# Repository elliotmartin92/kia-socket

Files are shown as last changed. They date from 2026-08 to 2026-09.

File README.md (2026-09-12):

# Automotive 120V AC Outlet Sub-Housing & Safety Interlock Mechanism
## Parametric 3D CAD Model & Generator Documentation

This repository contains the complete parametric CAD generation pipeline for the intermediate sub-housing baseplate and safety rocker mechanism of an **in-cabin automotive 120V AC US power outlet assembly**.

---

## System Architecture & Functional Overview

The complete automotive AC power outlet assembly consists of three primary mating components:
1. **Front Outlet Receptacle Bezel / Faceplate**: Exposed inside the vehicle cabin, providing the standard US NEMA 1-15 / 5-15 AC plug slots.
2. **Intermediate Sub-Housing Baseplate & Rocker Mechanism (THIS REPOSITORY)**:
   - **Primary Function 1: Current-Carrying Busbar & Terminal Retention**: Securely locates and retains the formed copper/brass contact pieces and busbar strips within precision guide brackets (Brackets 1–4) and backside slit channels, transferring high AC current from the rear electronics module directly into the front receptacle prongs.
   - **Primary Function 2: Active Plug Insertion Sensing & Power Safety Interlock**: Integrates a spring-biased/pivot rocker mechanism mounted inside heavy-duty retention towers. When the **right plug prong (blade)** is inserted into the outlet, it physically depresses the rocker's angled input cam tab ($105^\circ$ direct rocker arm). This rotates the pivot shaft in its cradles, driving the extended plunger arm downward ($Z \le -6.50\text{ mm}$) through the baseplate floor pass-through hole into a PCB-mounted tactile microswitch. This signals the inverter/control module that a plug is physically seated, ensuring the outlet **delivers 120V AC power only when a plug is actively inserted** (preventing idle power draw and electric shock hazards).
3. **Rear Electronics / Inverter & Control Board Module**: Houses the DC-to-AC power inverter, logic controller, supply terminal feeds, and the momentary interlock switch.

---

## 1. Quick Start & Regeneration Commands

To rebuild all 3D CAD assets and 2D/3D annotated blueprints from source:

```bash
# Build main baseplate CAD models (part.stl, part.obj, complete_assembly.stl)
py -3 build_part.py

# Build anti-spreading tower prong clamps (tower_clamp.stl, tower_clamps_pair.stl)
py -3 build_clamp.py

# Generate high-resolution dimensioned feature blueprints (labeled_part_preview.png)
py -3 generate_labeled_preview.py
```

### Generated Output Files
| File | Description |
| :--- | :--- |
| **`part.stl`** / **`part.obj`** | Main baseplate with **100% planar flat bottom ($Z = 0.00\text{ mm}$)** for support-free 3D printing. Tower prongs remain 100% solid and full-thickness, featuring robust additive external side retention ledges (**$+0.70\text{ mm}$ protrusion in $X$**, $Z \in [12.40, 13.60]\text{ mm}$) on outer lateral faces. Baseplate floor features enlarged $2.90 \times 5.10\text{ mm}$ female detent sockets for slit inserts. |
| **`shaft_rocker.stl`** / **`shaft_rocker.obj`** | Separate 3D-printable enlarged heavy-duty shaft/rocker mechanism with $\varnothing 2.80\text{ mm}$ axle pins, $\varnothing 4.20\text{ mm}$ hub, input cam, and $\ge 6.5\text{ mm}$ reach plunger. Pre-oriented flat on build bed ($Z = 0.00\text{ mm}$). |
| **`shaft_rocker_assembled.stl`** | Shaft/rocker mechanism positioned in exact assembly coordinates seated in the towers. |
| **`shaft_rocker.scad`** | OpenSCAD parametric source file for the shaft/rocker mechanism. |
| **`tower_clamp_bridge.stl`** / **`tower_clamp.stl`** | **Unified 1-Piece Monolithic Bridge Clamp**: Single unified component joining Left and Right clamps across a **$14.10\text{ mm}$ rigid rear gantry span** ($X \in [2.20, 16.30]\text{ mm}$). Both sides **mutually anchor each other**, clamping both towers from their outer lateral faces with **$0.65\text{ mm}$ deep inward undercut snap hooks** at $Z = 12.40\text{ mm}$ (providing $>4.5\times$ greater mechanical retention area; physically impossible to rock or fall off). Features clearance arches over both $\varnothing 2.80\text{ mm}$ axle pins ($\ge 0.30\text{ mm}$ radial air gap, zero pin friction!). Pre-oriented flat on print bed ($Z = 0.00\text{ mm}$, $85.15\text{ mm}^3$ volume, 100% watertight, support-free, $\sim 3\text{ min}$ print time). |
| **`tower_clamp_left.stl`** / **`tower_clamp_right.stl`** | Individual Left and Right clamp variants for modular installation. |
| **`tower_clamps_pair.stl`** | Pre-arranged pair of individual clamps on a single build plate. |
| **`tower_clamp.scad`** | OpenSCAD parametric source file for the tower clamps. |
| **`slit_insert.stl`** / **`slit_insert.obj`** | Separate 3D-printable backside slit wall insert with enlarged, sliceable registration key (**$2.60 \times 4.80\text{ mm}$** with solid **$0.70\text{ mm}$ walls**, impossible to drop in slicing) and $0.60\text{ mm} \times 45^\circ$ non-breaching polarization corner bevel. |
| **`slit_inserts_pair.stl`** | Two inserts pre-arranged side-by-side on a single build plate for 1-click 3D printing. |
| **`cooling_tower.stl`** / **`cooling_tower.obj`** | Sacrificial cooling column ($\varnothing 8.00\text{ mm} \times 20.50\text{ mm}$ tall) to guarantee dedicated cooling time per layer on delicate baseplate tower tips ($Z = 14.09\text{ mm}$) and shaft rocker tips ($Z = 19.86\text{ mm}$). |
| **`complete_assembly.stl`** / **`complete_assembly.obj`** | Complete 1-click 3D print plate with the main baseplate, both separate slit inserts, shaft rocker, sacrificial cooling tower, and the **Unified Monolithic Bridge Clamp** pre-arranged side-by-side on the **same flat print plane ($Z = 0.00\text{ mm}$)**. |
| **`part.scad`** | OpenSCAD source file representing the exact baseplate geometry. |
| **`labeled_part_preview.png`** | 3-panel blueprint showing top-down dimensioned feature map, 3D isometric assembly, and kinematic stroke cross-section. |
| **`part_preview.png`** | 3-panel multi-angle view (Top-Down, 3D Perspective, Bottom View). |

---

## 2. Coordinate System & Global Units

- **Units**: All dimensions are in **millimeters ($\text{mm}$)**.
- **Origin $(0, 0, 0)$**: Geometric center of the main body circle/profile.
- **Scale Factor**: Calibrated from SVG pixel coordinates:
  $$\text{SCALE} = 0.349787\text{ mm/pixel}, \quad X_0 = 128.65\text{ px}, \quad Y_0 = 128.65\text{ px}$$
- **$Z$-Axis Elevations (Main Part)**:
  - $Z = 0.00\text{ mm}$: 100% Flat build-plate datum (zero support needed under main floor).
  - $Z \in [0.00, 1.00]\text{ mm}$: Solid base floor plate ($1.00\text{ mm}$ thick).
  - $Z \in [1.00, 1.50]\text{ mm}$: Internal floor stiffener grid ribs ($0.50\text{ mm}$ tall).
  - $Z \in [1.00, 4.60]\text{ mm}$: Guide brackets ($4.60\text{ mm}$ total height).
  - $Z \in [1.00, 6.77]\text{ mm}$: Outer perimeter wall, snap clip stems, bottom arch wall, and bridge rib ($6.77\text{ mm}$ height).
  - $Z \in [1.00, 10.50]\text{ mm}$: Center curved feature with reinforced solid core and flat base ($10.50\text{ mm}$ total height).
  - $Z \in [1.00, 14.09]\text{ mm}$: Shaft support towers ($13.09\text{ mm}$ height above floor, total $14.09\text{ mm}$).
- **Separate Slit Insert Dimensions**:
  - $Z \in [0.00, 2.47]\text{ mm}$: Wall body ($3.80\text{ mm} \times 5.60\text{ mm}$ outer, $1.20\text{ mm} \times 3.50\text{ mm}$ inner clearance channel for $0.77\text{ mm} \times 3.10\text{ mm}$ part).
  - $Z \in [2.47, 3.32]\text{ mm}$: Indexing registration key ($2.00\text{ mm} \times 4.30\text{ mm} \times 0.85\text{ mm}$) with continuous $1.20\text{ mm} \times 3.50\text{ mm}$ core.

---

## 3. Comprehensive Feature Specifications

```
                              TOP TAB (8.20mm Wide, fits 8.33mm Gap)
                              +-------------------+
                             /                     \
                            /   [TOWER 1] [TOWER 2] \  <-- Shaft Axis (Y = 9.28mm, Z = 12.59mm)
           Snap Clip (135°) |      (2.45mm throat)  | Snap Clip (45°)
                            |   [Through-Hole]      |
                            |   5.35 x 4.51 mm      |
                            |                       |
       Left Side Ear (7.70)-|   [BRACKETS]          |- Right Side Ear (7.70mm Wide, fits 8.30mm Gap)
                            |   [CENTER ARCH WALL]  |
                            |   (10.50mm tall)      |
          Snap Clip (211.3°)|                       | Snap Clip (327.5°)
                            \   [SLIT 1]  [SLIT 2]  / (4.42mm from ears, 8.47mm from tabs)
                             \  1.20x3.50 1.20x3.50/
                              +---+             +---+
                              |   | [U-ARCH 5mm]|   |
                              |   | (7.95mm H)  |   |
                              +---+-------------+---+
                              LEFT TAB       RIGHT TAB
```

### 3.1. Bottom Central U-Arch & Inset Wall (Config 1)
- **Arch Interior Clearance Width**: **$5.00\text{ mm}$** ($R_{\text{inner}} = 2.50\text{ mm}$, centered on $X \in [-2.50, +2.50]\text{ mm}$).
- **Arch Wall Thickness**: **$1.20\text{ mm}$** ($R_{\text{outer}} = 3.70\text{ mm}$, $X \in [-3.70, +3.70]\text{ mm}$).
- **Total Outer Height in $Y$**: **$7.95\text{ mm}$**
  - Base at Inset Bottom Exterior Wall: $Y = -16.650\text{ mm}$
  - Outer Arch Apex: $Y = -8.700\text{ mm}$ ($-16.650 + 7.950\text{ mm}$)
  - Inner Arch Apex: $Y = -9.900\text{ mm}$ ($6.75\text{ mm}$ inner clearance height)
  - Semicircle Arc Center: $Y = -12.400\text{ mm}$ (Straight tangent legs: $4.25\text{ mm}$ in $Y$).
- **Inset Bottom Exterior Wall Notch**:
  - Inset depth: $1.889\text{ mm}$ in $+Y$ (from bottom tabs at $Y = -18.539\text{ mm}$ to inset wall at $Y = -16.650\text{ mm}$).
  - Notch outer sidewalls: placed at **$X = \pm 2.500\text{ mm}$**, aligning with the **interior sidewalls of the arch**.
  - Floor: Solid continuous $1.00\text{ mm}$ floor within the inset wall.

### 3.2. Shaft Support Towers with Heavy-Duty Reinforced Retention Cradles
- **Shaft Axis**: **$Y = 9.279\text{ mm}$, $Z = 12.59\text{ mm}$** ($\varnothing 3.00\text{ mm}$ shaft cradle socket, centered directly over the through-hole).
- **Left Tower**: $X \in [3.900, 5.400]\text{ mm}$ ($1.50\text{ mm}$ wall thickness).
- **Right Tower**: $X \in [13.100, 14.600]\text{ mm}$ ($1.50\text{ mm}$ thickness, $0.14\text{ mm}$ clearance right of through-hole).
- **Internal Clearance Between Towers**: **$7.70\text{ mm}$**.
- **Flared Trapezoidal Tower Profile (in Y-Z)**:
  - Base Length in $Y$: **$6.60\text{ mm}$** ($Y \in [6.250, 12.850]\text{ mm}$, shifted $-0.921\text{ mm}$ to align buttress base with top inner wall of Bracket 3 at $Y = 6.250\text{ mm}$).
  - Top Length in $Y$: **$5.63\text{ mm}$** ($Y \in [6.550, 12.180]\text{ mm}$).
- **Positive Heavy-Duty Snap-Fit Retention Cradle**:
  - Socket Diameter: **$\varnothing 3.00\text{ mm}$** (provides $0.20\text{ mm}$ running clearance with $\varnothing 2.80\text{ mm}$ shaft pin).
  - Retention throat constriction gap: **$2.60\text{ mm}$** ($0.20\text{ mm}$ firm positive mechanical interference with $\varnothing 2.80\text{ mm}$ shaft, $0.10\text{ mm}$ deflection per side to prevent snapping during insertion).
  - Wrap angle: **$240.0^\circ$** ($>60^\circ$ wrap beyond the equator), securely capturing and locking the axle against vertical ejection.
  - Wide $45^\circ$ lead-in bevel funnel expanding up to $3.73\text{ mm}$ opening at $Z = 14.09\text{ mm}$ for smooth self-centering downward press-fit insertion.
- **Left Tower Dual Lateral Buttress Struts**:
  - **Front Strut**: Base meets the top inner wall of Bracket 3 at **$Y = 6.250\text{ mm}$** ($X \in [1.90, 3.90\text{ mm}]$, $Y \in [6.250, 7.050\text{ mm}]$), sloping directly into the Left Tower at $Z = 13.70\text{ mm}$ with **zero encroachment into Bracket 3's sliding channel**.
  - **Rear Strut**: Full-height triangular rib ($1.20\text{ mm}$ thick in $Y$ at $Y \in [11.650, 12.850\text{ mm}]$, $X \in [1.90, 3.90\text{ mm}]$, $Z \in [1.00, 13.70\text{ mm}]$).
- **Right Tower Reinforcing Bridge Rib**: Spans $X \in [13.10, 20.00]\text{ mm}$ at $Y \in [7.50, 13.00]\text{ mm}$, connecting directly to the outer perimeter wall.

### 3.3. Curved Snap Clips (4x at $45^\circ, 135^\circ, 211.3^\circ, 327.5^\circ$)
- **Perimeter Positions**:
  - Top pair: $45^\circ$ and $135^\circ$ (halfway between top tab and side ears).
  - Bottom pair: **$211.3^\circ$ and $327.5^\circ$** (**$4.42\text{ mm}$ from respective side ears, $8.47\text{ mm}$ from respective bottom tabs**).
- **Wall Following**: Matches the exact curved contour of the outer ($R \approx 19.25\text{ mm}$) and inner ($R \approx 18.05\text{ mm}$) wall.
- **Beam Dimensions**: **$4.20\text{ mm}$ wide curved beam** (leaves $0.80\text{ mm}$ total margin / $0.40\text{ mm}$ per side for smooth insertion into $5.00\text{ mm}$ mating holes).
- **Flex Isolation**: Two $0.35\text{ mm}$ vertical through-slots (minimal printable clearance for a $0.4\text{ mm}$ nozzle) from $Z = 3.07\text{ mm}$ to $Z = 6.77\text{ mm}$ isolating the cantilever beam.
- **Hook Geometry ($Z \in [4.97, 6.77\text{ mm}$)**:
  - Undercut retention shelf at $Z = 4.97\text{ mm}$ projecting **$+2.49\text{ mm}$ radially outward** (refined $-0.10\text{ mm}$ from $2.59\text{ mm}$ to eliminate outer housing protrusion interference while maintaining deep engagement).
  - Sloped lead-in ramp tapering up to top outer wall apex at $Z = 6.77\text{ mm}$.
  - Inner wall face: 100% flush, smooth, continuous cylinder.
- **Built-In Sacrificial Support Towers (Twin-Prong Breakaway Fork Supports)**:
  - Sturdy base sitting flat on print bed ($Z = 0.00\text{ mm}$) with a wide adhesion foot ($1.80\text{ mm} \times 3.80\text{ mm}$) and solid lower trunk ($1.20\text{ mm} \times 3.40\text{ mm}$) up to $Z = 3.20\text{ mm}$.
  - **Twin Lateral Prongs & Prying Arch**: Splits into two vertical prongs centered at $Y = \pm 1.40\text{ mm}$ spanning across a $1.80\text{ mm}$ wide central prying arch window ($Z \in [3.20, 4.82]\text{ mm}$), directly supporting the outer lateral shelf corners ($0.25\text{ mm}$ margin to edges).
  - **Equal Contact Area ($0.90\text{ mm}^2$)**: Twin chisel breakaway tips ($2 \times [0.50\text{ mm} \times 0.90\text{ mm}] = 0.90\text{ mm}^2$, matching original area) at $Z = 4.94\text{ mm}$ ($0.03\text{ mm}$ micro-gap under the $Z = 4.97\text{ mm}$ shelf). Completely prevents edge droop while allowing effortless tool prying with zero marring.

### 3.4. Center Curved Feature with Reinforced Solid Core (Option 1)
- **Position**: Centered between Brackets 3 & 4 at $X_c = +6.279\text{ mm}$.
- **Width**: $4.30\text{ mm}$ ($X \in [4.129, 8.429]\text{ mm}$).
- **Depth in $Y$**: $1.62\text{ mm}$ (Base: $Y = -4.069\text{ mm}$, Apex: $Y = -2.449\text{ mm}$).
- **Offset**: $2.00\text{ mm}$ in $+Y$ above the horizontal bracket step datum ($Y = -6.069\text{ mm}$).
- **Monolithic Solid D-Shape Structure**:
  - Replaced the fragile $0.60\text{ mm}$ hollow C-shell with a **100% solid infill cross-section** ($5.46\text{ mm}^2$ solid area, $+52\%$ material increase).
  - Closed the bottom ($-Y$) with a **continuous solid flat back wall** along $Y = -4.069\text{ mm}$.
  - Preserves the identical top outer arc ($R_x = 2.15\text{ mm}, R_y = 1.62\text{ mm}$, apex at $Y = -2.449\text{ mm}$) with $+2.16\text{ mm}$ clearance to the plug blade.
  - Guaranteed clearance to OEM brass insert: **$+0.58\text{ mm}$ air gap** to the brass crossbar and **$+0.28\text{ mm}$ air gap** to Seating Rib 4.
  - Increases bending moment of inertia $I_{xx}$ by $+52\%$ ($0.658 \to 1.000\text{ mm}^4$) and shear fracture load capacity by $>3.6\times$, eliminating layer shear failures during disassembly.
- **Total Height**: **$10.50\text{ mm}$** ($Z \in [1.00, 10.50]\text{ mm}$).

### 3.5. Guide Brackets & Brass Seating Ribs (Looser Tolerances & 1.15mm Support Ribs)
- **Left Pair (Brackets 1 & 2)**: $X \in [-10.791, -1.766]\text{ mm}$.
- **Right Pair (Brackets 3 & 4)**: $X \in [+1.766, +10.791]\text{ mm}$.
- **Relaxed Looser Interior Tolerances (Brackets 1–4)**:
  - **Spine Channel Width ($X$)**: Widened from $6.856\text{ mm}$ to **$7.156\text{ mm}$** (provides **$+0.416\text{ mm}$ total sliding clearance** / $0.208\text{ mm}$ per side for the $6.74\text{ mm}$ OEM stamped brass contact strip, eliminating FDM print friction).
  - **Top Lead-In Throat Opening ($X$)**: Widened to **$3.500\text{ mm}$** ($+0.32\text{ mm} \text{ to } +0.35\text{ mm}$ wider funnel for smooth contact spring blade entry).
  - **Bottom Step Opening ($X$)**: Widened to **$3.800\text{ mm}$** ($+0.34\text{ mm}$ wider gap to easily pass the S-curved terminal leg).
  - **Internal Vertical Span ($Y$)**: Extended from $12.336\text{ mm}$ to **$12.600\text{ mm}$** ($Y \in [-6.200, +6.400]\text{ mm}$) to prevent axial binding.
  - **Top Hook Lead-In & Pocket ($Y$)**: Lower hook face raised to **$Y = 4.950\text{ mm}$**, upper pocket ceiling raised to **$Y = 6.400\text{ mm}$** (preserving full **$1.450\text{ mm}$** positive retention pocket depth).
- **Bracket Seating Ribs ($1.15\text{ mm}$ Elevation)**:
  - **Height**: **$1.15\text{ mm}$** protrusion above the floor ($Z \in [1.00, 2.15]\text{ mm}$) to elevate the brass contact piece.
  - **Inward Extension**: **$1.80\text{ mm}$** from each interior spine wall on both brackets of each pair.
  - **Central Open Corridor**: **$3.556\text{ mm}$** wide open central clearance along $X = \pm 6.28\text{ mm}$ for contact blade pinching and terminal pin clearance.
  - **Four Longitudinal $Y$ Stations**:
    - **Rib 1 (Top)**: Centered at **$Y = +5.250\text{ mm}$** ($Y \in [4.950, 5.550]\text{ mm}$), bottom edge meets the hook corner at $Y = 4.950\text{ mm}$ flush, forming a square seating corner under each hook.
    - **Rib 2**: Centered at **$Y = +1.950\text{ mm}$** ($Y \in [1.650, 2.250]\text{ mm}$).
    - **Rib 3**: Centered at **$Y = -1.350\text{ mm}$** ($Y \in [-1.650, -1.050]\text{ mm}$).
    - **Rib 4 (Bottom)**: Centered at **$Y = -4.650\text{ mm}$** ($Y \in [-4.950, -4.350]\text{ mm}$).
- **Bracket Total Height**: $4.60\text{ mm}$ ($Z \in [1.00, 5.60]\text{ mm}$).
- **Nominal Wall Thickness**: $0.85\text{ mm}$ to $0.93\text{ mm}$.

### 3.6. Backside Slit Protruding Bosses & Press-Fit Detent Inserts (Approach B: 100% Untouched Wall & Polarized Key)
- **Mating Component Fitment**: Custom engineered to comfortably pass a **$0.77\text{ mm} \text{ (thick in X)} \times 3.10\text{ mm} \text{ (long in Y)}$** metal contact blade.
- **Continuous Internal Through-Channel**: Sized at **$1.20\text{ mm} \text{ (in X)} \times 3.40\text{ mm} \text{ (in Y)}$** through both the insert and baseplate (**$+0.43\text{ mm}$ in X, $+0.30\text{ mm}$ in Y** generous sliding clearance to eliminate FDM print shrinkage binding).
- **Exact Slit Alignments**:
  - Left Slit Socket: Centered at **$X = -7.853\text{ mm}, Y = -13.589\text{ mm}$** (centered on Bracket 1 datum line).
  - Right Slit Socket: Centered at **$X = +8.453\text{ mm}, Y = -13.589\text{ mm}$** (exact OEM design alignment matching the vehicle mating plug).
- **100% UNTOUCHED Main Housing Perimeter Wall**:
  - The outer perimeter wall is **100% solid, continuous, and uniform $1.20\text{ mm}$ thick everywhere from $Z = 1.00\text{ mm}$ to $6.77\text{ mm}$** with **zero pockets, zero reliefs, and zero notches**.
  - All clearance routing is handled entirely on the insert indexing key and matching baseplate floor socket.
- **Main Baseplate Detent Sockets**: Two **$2.20\text{ mm} \times 4.40\text{ mm}$** female detent sockets cut through the $1.00\text{ mm}$ baseplate floor with a **$45^\circ$ corner chamfer** on the bottom-right of the right socket (and bottom-left of the left socket) to contour along the inner perimeter wall with a **$0.35\text{ mm}$ clean clearance margin**.
- **Separate Slit Inserts (`slit_insert.stl` & `slit_inserts_pair.stl`)**:
  - **$2.20\text{ mm}$ Sloped Outer Shroud Body**: $15.8^\circ$ draft angle tapering from a $2.70\text{ mm} \times 4.80\text{ mm}$ base shoulder down to **$2.20\text{ mm} \text{ (width)} \times 4.20\text{ mm} \text{ (length)}$** at the outer bottom face ($Z = 0.00\text{ mm}$), ensuring the shroud sits flush inside the $X = 9.812\text{ mm}$ outer perimeter wall edge with zero collision.
  - **1-Way Polarized Chamfered Indexing Key**: $1.80\text{ mm} \times 4.00\text{ mm}$ raised boss ($0.85\text{ mm}$ tall, $Z \in [2.47, 3.32]\text{ mm}$) featuring a **$45^\circ$ chamfered indexing corner** that prevents inserting the part backwards or rotated $180^\circ$.
  - **Fit Clearance**: **$0.40\text{ mm}$ total clearance ($0.20\text{ mm}$ per side)** into the baseplate detent socket for smooth, firm press-fit seating without binding.
  - **Flush Horizontal Seating Shoulder**: Sits flat against the baseplate bottom face ($Z = 0.00\text{ mm}$).
- **Complete Assembly Build Plate Layout**: `complete_assembly.stl` arranges the main baseplate, both separate slit inserts, shaft rocker, and sacrificial cooling tower flat on the **same build plane ($Z = 0.00\text{ mm}$)** side-by-side for 1-click support-free 3D printing.

### 3.7. Left and Right Side Ears (8.20mm Width for 8.30mm Enclosure Gap)
- **Position**: Left Side Ear at $X \approx -21.075\text{ mm}$, Right Side Ear at $X \approx +20.200\text{ mm}$ (centered at $Y = 0.00\text{ mm}$).
- **Outer Width in $Y$**: **$8.20\text{ mm}$** ($Y \in [-4.10, +4.10]\text{ mm}$).
- **Mating Enclosure Gap**: $8.30\text{ mm}$ (leaves $0.10\text{ mm}$ total sliding clearance / $0.05\text{ mm}$ per side for a smooth, bind-free sliding fit into the chassis guide slots).

### 3.8. Top Tab (8.20mm Width for 8.33mm Enclosure Gap)
- **Position**: Symmetrically centered along $X = 0.00\text{ mm}$ ($X \in [-4.10, +4.10]\text{ mm}$, Top apex at $Y = 20.01\text{ mm}$).
- **Outer Width in $X$**: **$8.20\text{ mm}$**.
- **Mating Enclosure Gap**: $8.33\text{ mm}$ (leaves $0.13\text{ mm}$ total sliding clearance / $0.065\text{ mm}$ per side for a clean, centered fit into the chassis top indexing slot).

### 3.9. Internal Floor Stiffener Grid
- **Pitch**: $5.20\text{ mm}$ (in $X$) $\times 3.20\text{ mm}$ (in $Y$).
- **Thickness & Height**: $0.60\text{ mm}$ thick, $0.50\text{ mm}$ tall ($Z \in [1.00, 1.50]\text{ mm}$).
- **Connectivity**: Connects directly into outer perimeter walls; excluded under bracket pairs and bottom zone ($Y < -7.17\text{ mm}$).

### 3.10. Enlarged Heavy-Duty Shaft & Rocker Mechanism (PCB Button Actuator)
- **Pivot Axle & Structural Core**:
  - Precision $\varnothing 2.80\text{ mm}$ bearing ends ($R = 1.40\text{ mm}$, $0.10\text{ mm}$ radial clearance fit inside $\varnothing 3.00\text{ mm}$ tower cradles) snapping firmly through the $2.60\text{ mm}$ tower throat ($+47\%$ diameter, $4.72\times$ higher torsional rigidity over $\varnothing 1.90\text{ mm}$).
  - **$\varnothing 4.20\text{ mm}$ heavy-duty structural hub barrel** spanning $X \in [5.50, 13.00]\text{ mm}$ to eliminate shaft deflection, shear, or twisting under spring/switch load.
- **Heavy-Duty Filleted Output Plunger Arm**:
  - **Width in $X$**: Widened to **$4.40\text{ mm}$ in $X$** (centered at $X = 10.284\text{ mm}$ in the $5.35\text{ mm}$ through-hole with $0.48\text{ mm}$ lateral clearances).
  - **Root Thickness in $Y$**: Thickened to **$3.80\text{ mm}$ at the shaft junction** blending into the $\varnothing 4.20\text{ mm}$ central hub barrel to eliminate bending under plug prong insertion.
  - **Tip Contact**: Smoothly tapers to a $2.00\text{ mm}$ nose diameter ($R = 1.00\text{ mm}$) at the switch contact point.
  - **Reach & Stroke**: Reaches **$\ge 6.50\text{ mm}$ below the outer bottom face of the baseplate ($Z \le -6.50\text{ mm}$)**.
  - **Kinematics**: Rotates clockwise around the $Y = 9.279\text{ mm}, Z = 12.59\text{ mm}$ pivot axis to actuate the Y-axis oriented PCB tactile switch with zero through-hole interference.
- **Reinforced Convex Crowned Input Cam & Full-Span Monolithic Gusset Web**:
  - $2.70\text{ mm}$ wide input cam tab aligned with the right plug prong insertion path ($X = 7.05\text{ mm}$).
  - **Convex Crowned Profile ($+0.45\text{ mm}$ crown arc)**: Acts as a true kinematic cam profile against the straight downward-moving plug blade, maintaining continuous rolling tangency and uniform normal force across all $0^\circ \to 10^\circ$ actuation angles without edge-digging or stick-slip friction.
  - Monolithic structural gusset web spanning continuously across the entire opening between the towers ($X \in [5.60, 12.90]\text{ mm}$).

---

## 4. Key Scripts & Code Architecture

- **`build_part.py`**:
  - `get_exact_base_polygon()`: Parses SVG path, aligns bottom notch, and creates through-holes.
  - `create_arch_wall_poly()`: Builds the $7.95\text{ mm}$ tall, $5.00\text{ mm}$ inner width U-arch.
  - `build_clean_shaft_towers_mesh()`: Generates both towers with the $1.65\text{ mm}$ retention cradle.
  - `build_left_tower_struts_mesh()`: Creates the triangular buttress struts on the left tower.
  - `create_center_curved_feature_poly()`: Generates the $10.50\text{ mm}$ tall center feature.
  - `build_exact_3d_model()`: Assemblies all components and cuts flex slots into the wall.
  - `build_indexed_assembly_mesh()`: Places main baseplate, slit inserts, and shaft rocker flat on $Z = 0.00\text{ mm}$ print plate.
- **`build_shaft.py`**:
  - `build_shaft_rocker_mesh()`: Parametric generator for the shaft/rocker mechanism with customizable axle diameter, plunger reach ($Z \le -6.5\text{ mm}$), cam angle, and print bed orientation.
  - `export_shaft_scad()`: Generates parametric OpenSCAD source file (`shaft_rocker.scad`).
- **`generate_labeled_preview.py`**:
  - Generates the 3-panel labeled blueprint: Top-down feature map, 3D isometric assembly, and side kinematic stroke cross-section.
- **`testing/`**:
  - Dedicated directory containing unit tests, dimensional verification scripts, geometric exploration scripts, and inspection renders.

---

## 5. Development & Testing Guidelines

- **Testing Files Location**: All new test scripts, verification scripts, geometric inspection scripts, and one-off diagnostic visualization scripts/renders **must be created inside the `testing/` directory**.
- **Root Directory Cleanliness**: The project root directory is strictly reserved for core build pipeline generators (`build_part.py`, `build_shaft.py`, `generate_labeled_preview.py`), source geometry inputs (`part.svg`), final CAD exports (`.stl`, `.obj`, `.scad`), final documentation previews (`part_preview.png`, `labeled_part_preview.png`), and documentation (`README.md`).

---

## 6. Print Iteration History & Notes

### Version 6 (v6)
- **Tower Clip Snapping Fix**:
  - Relaxed retention cradle throat width from $2.05\text{ mm}$ to **$2.60\text{ mm}$** ($0.20\text{ mm}$ total interference with $\varnothing 2.80\text{ mm}$ shaft pin, $0.10\text{ mm}$ deflection per jaw).
  - Reduces insertion strain by **$73\%$**, preventing inter-layer delamination/snapping on 3D-printed cantilever jaws while maintaining a **$240.0^\circ$ positive retention wrap angle**.
  - Widened the top self-centering lead-in funnel to **$3.73\text{ mm}$** for smooth, guided downward insertion.
- **Shaft Rocker Support Reduction & Print Orientation**:
  - Reoriented `shaft_rocker.stl` to **Cam Face Down (`Rot X = 198.6°`)**.
  - Wide flat face of the input cam tab ($2.7\text{ mm} \times 6.8\text{ mm}$) rests directly on the build bed ($Z = 0.00\text{ mm}$), increasing bed contact area **$7\times$** ($25.48\text{ mm}^2$).
  - 3-rib fork array points upward, **completely eliminating trapped support material inside the narrow inter-rib slots**.
  - Pivot axle pins remain horizontal for maximum tensile/bending strength with zero support scars on the cylindrical bearing surfaces.

### Version 7 (v7)
- **Printed v7 Lever & Extended Heat Break Tower**:
  - Validated 3D printing of the reoriented v7 shaft/lever mechanism (`shaft_rocker.stl`).
  - Extended sacrificial cooling / heat break tower to **$20.50\text{ mm}$** ($\varnothing 8.00\text{ mm}$) to match and exceed the full $19.86\text{ mm}$ build height of the v7 lever, providing dedicated per-layer nozzle travel and thermal stabilization for the finest tips of both the lever plunger and baseplate retention towers.
- **Perimeter Snap Clips +1.00mm Radial Extension**:
  - Increased snap clip hook overhang depth from $1.59\text{ mm}$ to **$2.59\text{ mm}$** (`CLIP_HOOK_DEPTH`), providing deeper latch engagement into the mating female enclosure windows.
  - Centered and widened built-in breakaway sacrificial support pillars ($1.20\text{ mm} \times 2.20\text{ mm}$) directly beneath the $2.59\text{ mm}$ horizontal shelf overhang.
- **Convex Crowned Input Cam Profile**:
  - Upgraded the straight linear cam ramp on the shaft rocker to a **$+0.45\text{ mm}$ convex crown arc**.
  - Maintains continuous rolling tangency with the straight-inserted plug blade throughout dynamic rotation ($0^\circ \to 10^\circ$), preventing edge-digging and providing smooth, linear mechanical advantage.

### Version 8 (v8)
- **Direct Straight Belly Cam for OEM Brass Pinching Mechanism**:
  - Direct integration with the physical OEM stamped brass pinching contact clips in Brackets 3 & 4 (Hot Terminal: $6.74\text{ mm}$ wide in $X$, $14.40\text{ mm}$ tall above floor, $5.00\text{ mm}$ internal belly cavity, $1.00\text{ mm}$ pinch throat, $4.30\text{ mm}$ top V-flare opening).
  - **Re-centered on Hot Blade Axis**: Input cam centered precisely at **$X = 6.28\text{ mm}$**.
  - **100% Full Structural Width Preserved**: Retains the full **$2.70\text{ mm}$ width** in $X$ with $+2.02\text{ mm}$ lateral clearance inside the $6.74\text{ mm}$ brass strip boundaries (zero need to narrow the rocker).
  - **Direct Solid $2.80\text{ mm}$ Cantilever Beam**: Eliminates arched sections in favor of a straight, rigid structural beam sloping directly from the $\varnothing 4.20\text{ mm}$ hub barrel down into the $5.00\text{ mm}$ wide internal belly cavity ($Z \in [5.0, 7.5]\text{ mm}$).
  - **Kinematic Safety Interlock**: Contact initializes as the plug blade tip emerges from the $Z = 9.40\text{ mm}$ pinch throat at **$Z_{\text{tip}} = 7.20\text{ mm}$**, fully triggering the PCB tactile switch at **$Z_{\text{tip}} = 6.40\text{ mm}$ ($\theta = 6.15^\circ$)**.

### Version 9 (v9) & Reinforced Clamps
- **Side-Wrapping Anti-Spreading Tower Prong Clamps (`tower_clamp_left.stl`, `tower_clamp_right.stl`, `tower_clamp_bridge.stl`)**:
  - **Root Cause Remediation**: Permanently eliminates the primary OEM failure mode where the retention cradle prongs flex and spread apart in $Y$ under repeated plug insertion loads and EV cabin summer heat, allowing the shaft to unseat in $+Z$ and the interlock switch to fail.
  - **100% Solid Un-Notched Tower Prongs**: Zero cuts, notches, or grooves are added to the tower prongs. The prongs retain their full $1.50\text{ mm}$ wall thickness and monolithic structural integrity with zero notch stress concentrations at the root.
  - **Additive External Side Retention Ledges**: Adds a horizontal retention bead ($+0.70\text{ mm}$ in $X$, $Z \in [12.40, 13.60]\text{ mm}$) to the *outer lateral faces* of the towers ($X = 3.90\text{ mm}$ Left, $X = 14.60\text{ mm}$ Right). Because it is an additive outward bump on the lateral face, it adds material rather than thinning the prongs in their bending direction.
  - **Reinforced Heavy-Duty Anti-Flex Architecture**:
    - **Thickened Bridge Roof**: Increased from $0.90\text{ mm}$ to **$1.60\text{ mm}$** ($+78\%$ thickness, $>5.6\times$ higher out-of-plane bending stiffness).
    - **Reinforced Outer Cheeks**: Increased from $1.00\text{ mm}$ to **$1.60\text{ mm}$** (4 solid perimeters on a 0.4mm nozzle).
    - **Dual-Layer Continuous Backplate**: Outer $0.80\text{ mm}$ cheek is a 100% continuous solid plate spanning the entire $4.45\text{ mm}$ length in $Y$, backed by an inner $0.80\text{ mm}$ arched plate, completely eliminating the thin-wall hinge flexure.
    - **Thickened U-Saddle Tension Walls**: Increased from $1.15\text{ mm}$ to **$1.40\text{ mm}$** for extreme hoop constraint.
    - **Precision Snug Fit Across Prongs**: $5.67\text{ mm}$ inner span hugging the $5.63\text{ mm}$ tower top span with zero rattle.
  - **Positive Lateral Undercut Snap-Lock**: Dual inward snap hooks at $Z = 12.35\text{ mm}$ ($0.05\text{ mm}$ clearance past the $Z = 12.40\text{ mm}$ tower ledge) featuring a $35^\circ$ push-on lead-in chamfer. Once pushed down, it snaps under the additive side ledge with an audible, positive mechanical click.
  - **Zero Axle Pin Friction**: Pin tips end at $X = 3.45\text{ mm}$ (Left) and $X = 15.05\text{ mm}$ (Right), maintaining $\ge 0.25\text{ mm}$ clear air gap from the side cheeks. The pin rotates with complete, untouched freedom and **zero extra friction**.
  - **Positive Pin Hold-Down Keel**: Includes a central stabilizing keel descending to $Z = 14.02\text{ mm}$ directly into the throat funnel, maintaining a $0.07\text{ mm}$ running gap above the $\varnothing 2.80\text{ mm}$ pivot pin inside the cradle to stop the pin from lifting out of the cradle.
  - **Unified Monolithic Bridge Gantry (`tower_clamp_bridge.stl`)**: Features a heavy-duty $1.50\text{ mm} \times 2.19\text{ mm}$ rear tie bar linking Left and Right towers across a rigid monolithic gantry frame.
  - **1-Click Support-Free Printing**: Pre-oriented flat on print bed with top bridge roof down ($Z = 0.00\text{ mm}$). Zero overhangs, vertical walls, 100% support-free 3D printing.
  - **Complete Assembly Build Plate**: `complete_assembly.stl` includes the unified monolithic bridge clamp pre-positioned on the $Z = 0.00\text{ mm}$ print plane alongside the baseplate, inserts, rocker, and cooling tower.

- **Refined Snap Clip Radial Protrusion & Twin-Prong Breakaway Fork Supports**:
  - **-0.10mm Protrusion Calibration**: Refined `CLIP_HOOK_DEPTH` from $2.59\text{ mm}$ to **$2.49\text{ mm}$**, perfectly eliminating slight outer housing interference during enclosure insertion while retaining strong positive latch engagement.
  - **Twin-Prong Breakaway Fork Support**: Replaced the center chisel support pillar with a bifurcated twin-prong support tower with a $1.80\text{ mm}$ central prying arch window.
  - **Equal Contact Area ($0.90\text{ mm}^2$) & Edge Support**: Two discrete $0.50\text{ mm} \times 0.90\text{ mm}$ chisel tips directly support the lateral outer shelf edges ($0.25\text{ mm}$ from corners), eliminating overhang droop while matching the original total contact area ($0.90\text{ mm}^2$) and providing an open window for effortless snap-off removal.

---

## 7. Future Optimization & Tweak Candidates

### 7.1. Center Curved Feature Active Guide Funnel
- **Current Geometry**: The $10.50\text{ mm}$ tall Center Curved Feature (Option 1A, Apex at $Y = -2.45\text{ mm}$) has a **$+2.16\text{ mm}$ clear air gap** from the inserted hot plug blade ($Y \in [-0.29, +6.07]\text{ mm}$), acting as a low-friction dielectric barrier and fail-safe backstop at $>7.5^\circ$ tilt without causing insertion drag or 3-point kinematic binding.
- **Potential Tweak**: If physical blade guidance toward the cam needs to be tightened in future revisions without relying solely on the front faceplate bezel slots:
  - Add a **$30^\circ$ lead-in funnel bevel** to the top rim of the feature ($Z \in [8.00, 10.50]\text{ mm}$).
  - Optionally extend the curved wings $+1.00\text{ mm}$ in $+Y$ (reducing the gap from $2.16\text{ mm}$ to $1.16\text{ mm}$) to serve as an active entry funnel while preserving bottom clearance for the electrical contact clips.

### 7.2. Plug Insertion Kinematics & Dynamic Verification Suite
- **Kinematic Simulation Script**: [`testing/model_plug_insertion.py`](file:///c:/Users/Elliot/Documents/antigravity/kind-bardeen/testing/model_plug_insertion.py) models the complete step-by-step NEMA 5-15 plug insertion, computing shaft rotation $\theta(Z)$, mechanical advantage ($4.64\times$), jamming margin ($\tan\alpha = 0.416 \ll 1/\mu$), and switch actuation ($Z_{\text{trip}} = 13.30\text{ mm}$ with $8.70\text{ mm}$ lead-in before electrical busbar entry at $Z \le 4.60\text{ mm}$).
- **Inspection Blueprints**:
  - `testing/plug_insertion_simulation.png`: 4-panel comprehensive dynamic simulation blueprint.
  - `testing/curved_feature_blade_clearance.png`: 2D planar dimensioned clearance map between blade prongs and the Center Curved Feature.
  - `testing/3d_plug_insertion_view.png`: 3D isometric overview and closeup of plug blade engagement.

---

## 8. Data Sources & OEM Teardown References

The reverse-engineering, geometric reconstruction, and reinforcement redesign in this repository are based on physical teardowns and community diagnostic data from the Kia EV6 in-cabin 120V AC (V2L) power outlet assembly:

### 8.1. Reddit Community Teardown & Diagnostic Thread
- **Post URL**: [r/KiaEV6 - Internal outlet fix (for free)](https://www.reddit.com/r/KiaEV6/comments/1n9e8ex/internal_outlet_fix_for_free/p5gh9tp/?screen_view_count=2)
- **Discussion Context**:
  - Documents the primary OEM failure mode of the under-rear-seat 120V AC Vehicle-to-Load (V2L) receptacle.
  - **Failure Mechanism**: The factory OEM plastic interlock lever is prone to fatigue, bending, or hinge spreading, which prevents the actuator arm from reaching down to depress the PCB-mounted tactile microswitch upon plug insertion. Because the onboard inverter requires switch closure to energize the high-voltage busbars, the outlet fails to provide power.
  - **Reverse Engineering & Pinout Details**: [Comment p5gh9tp](https://www.reddit.com/r/KiaEV6/comments/1n9e8ex/internal_outlet_fix_for_free/p5gh9tp/) and community contributions document the 6-pin low-voltage connector wiring, vehicle V2L interlock loop, seat removal steps ([Seat Disassembly Video Guide](https://www.youtube.com/watch?v=jpA-26kksXE)), and multimeter diagnostic checks across switch terminals to verify switch closure.
  - Establishes the motivation for engineering a heavy-duty, reinforced 3D-printable replacement sub-housing baseplate and shaft rocker rather than bypassing the safety switch.

### 8.2. Imgur Teardown Photo Album
- **Album URL**: [Kia EV6 Internal 120V Outlet Complete Teardown Album](https://imgur.com/a/pbAzoX3)
- **Annotated Image Reference Breakdown**:
  - `IaPuDNn` ([Photo 1](https://i.imgur.com/IaPuDNn.jpeg)): Assembled outlet front bezel and receptacle faceplate.
  - `pwVL1Z3` ([Photo 2](https://i.imgur.com/pwVL1Z3.jpeg)): Assembled outlet bottom housing showing fascia release clips.
  - `qxmFKgz` ([Photo 3](https://i.imgur.com/qxmFKgz.jpeg)): Rear connector interface showing high-voltage inverter plug socket and low-voltage harness connector.
  - `44mUCFQ` ([Photo 4](https://i.imgur.com/44mUCFQ.jpeg)): Front fascia trim plate detached.
  - `SjSNtO0` ([Photo 5](https://i.imgur.com/SjSNtO0.jpeg)): Main housing top perimeter locking clips.
  - `grxBHsa` ([Photo 6](https://i.imgur.com/grxBHsa.jpeg)): Main housing bottom perimeter locking clips.
  - `Pdtbqbm`, `FjVlOF3`, `sKEneQZ`, `6eXiu5F` ([Photos 7–10](https://i.imgur.com/6eXiu5F.jpeg)): Perimeter latch release and housing separation sequence.
  - `IoqkvCh` ([Photo 11](https://i.imgur.com/IoqkvCh.jpeg)): Rear housing shell removed, revealing PCB power terminals and connector interface.
  - `o7b2HIs`, `pAvdBUj` ([Photos 12–13](https://i.imgur.com/pAvdBUj.jpeg)): Full exploded disassembly showing the intermediate sub-housing baseplate, conductive busbar contacts, and PCB.
  - `QmMDxbP` ([Photo 14](https://i.imgur.com/QmMDxbP.jpeg)): Front plug contact assembly showing high-current copper contact clips and the OEM safety rocker mechanism positioned beneath the hot prong channel.
  - `fpuwcJR` ([Photo 15](https://i.imgur.com/fpuwcJR.jpeg)): Sub-housing baseplate aligned with PCB, demonstrating the plunger stroke path entering the pass-through window directly above the tactile microswitch.
  - `VVKc3SP` ([Photo 16](https://i.imgur.com/VVKc3SP.jpeg)): PCB tactile switch closeup and multimeter test points (switch leg to data pin #2) for interlock verification.
  - `drXwtPB`, `EuqSTMx` ([Photos 17–18](https://i.imgur.com/drXwtPB.png)): Internal wiring schematics and structural dimensional reference.

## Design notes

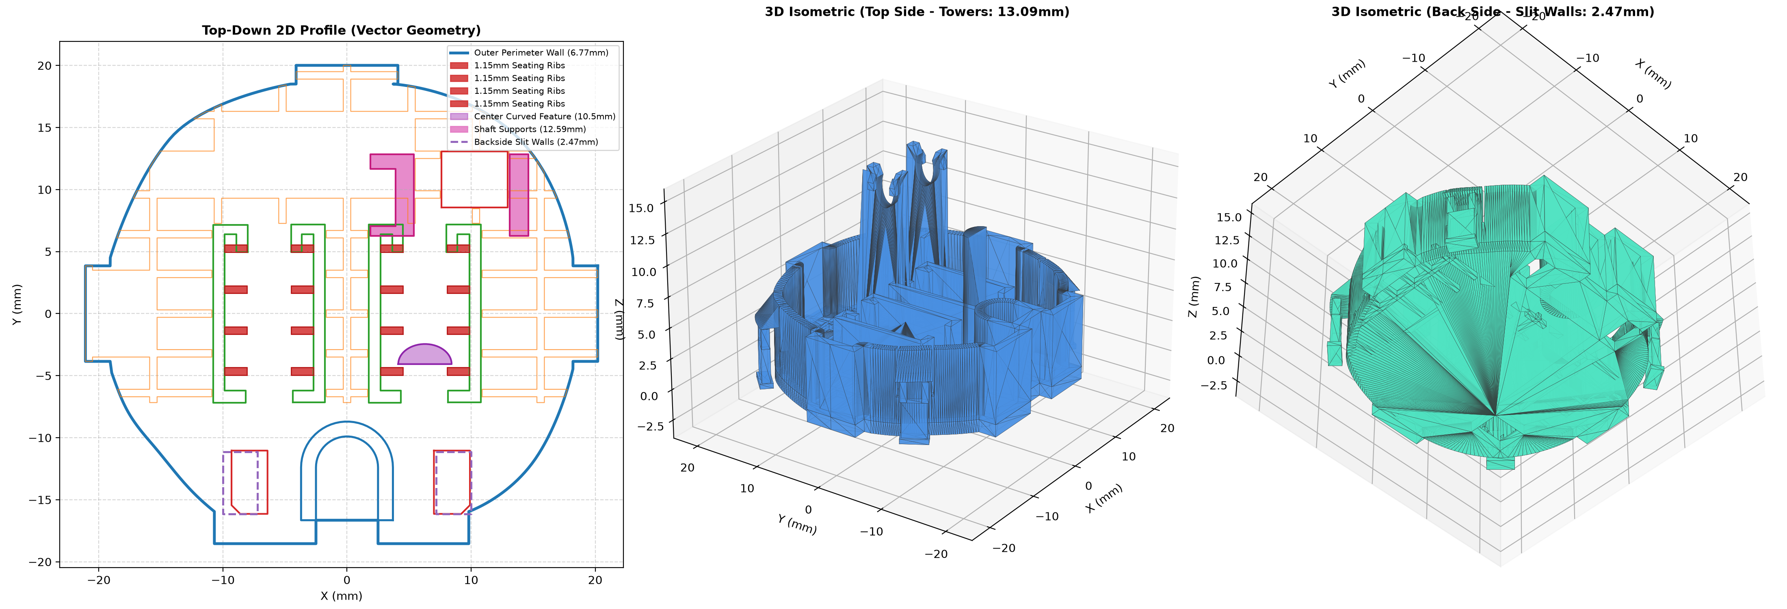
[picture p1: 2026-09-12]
part_preview.png

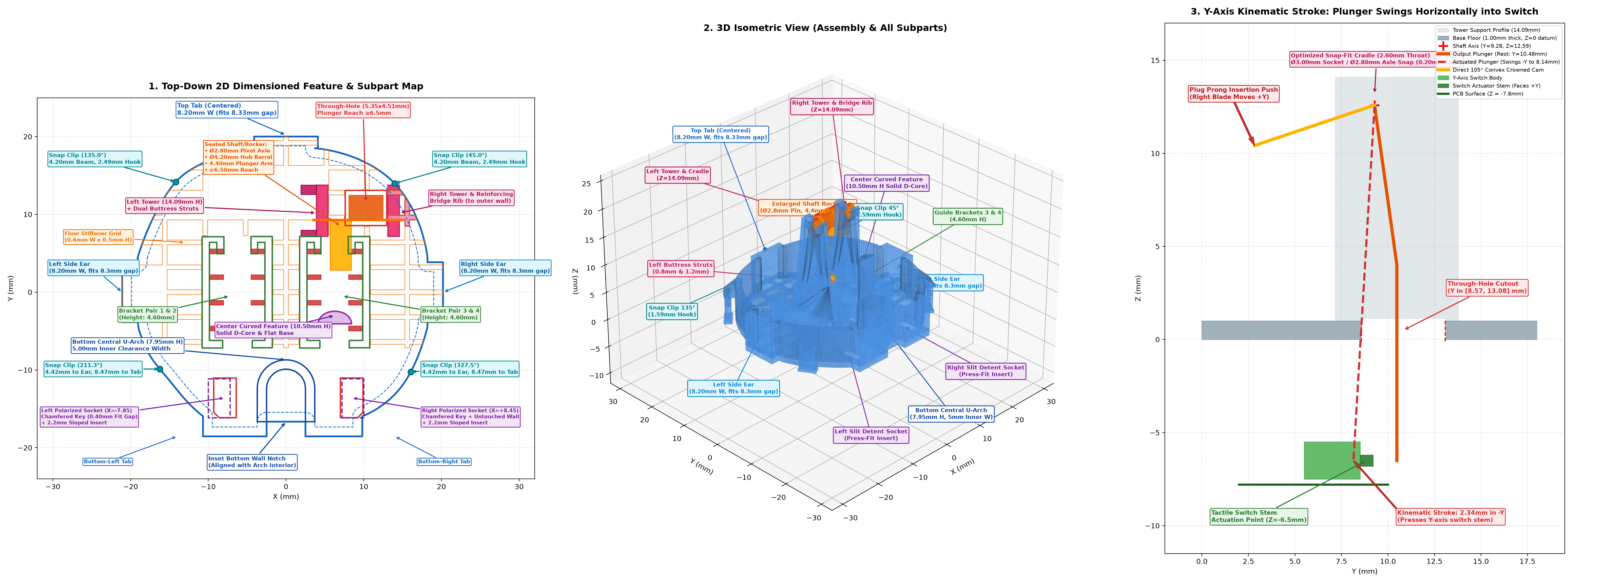
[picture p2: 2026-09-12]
labeled_part_preview.png

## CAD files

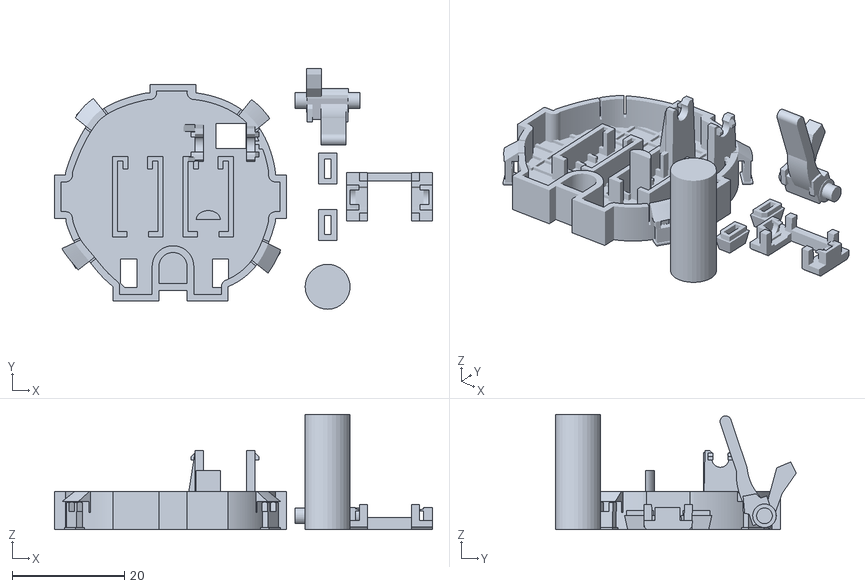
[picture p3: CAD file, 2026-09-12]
complete_assembly.stl
67.2 x 42.8 x 20.5

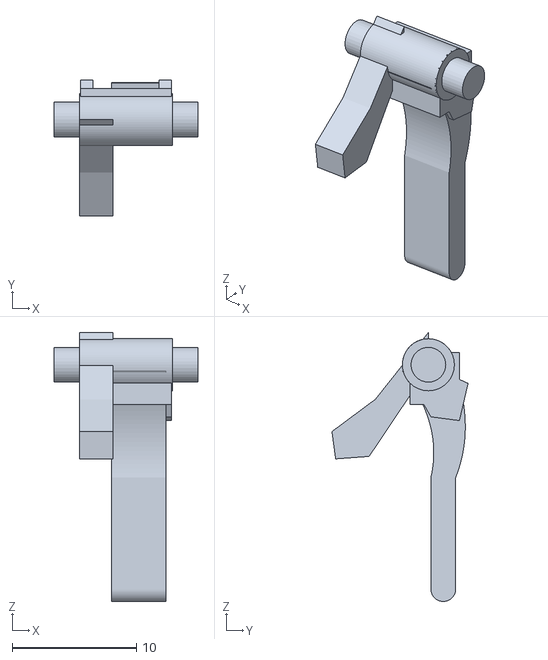
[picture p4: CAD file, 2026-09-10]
shaft_rocker_assembled.stl
11.6 x 11.0 x 21.7

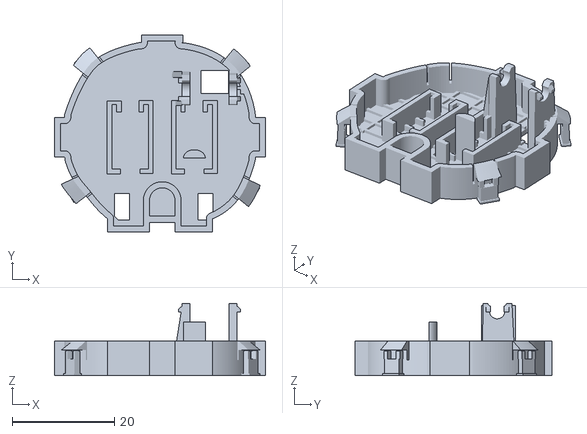
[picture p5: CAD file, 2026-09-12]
part.stl
41.3 x 38.5 x 14.1

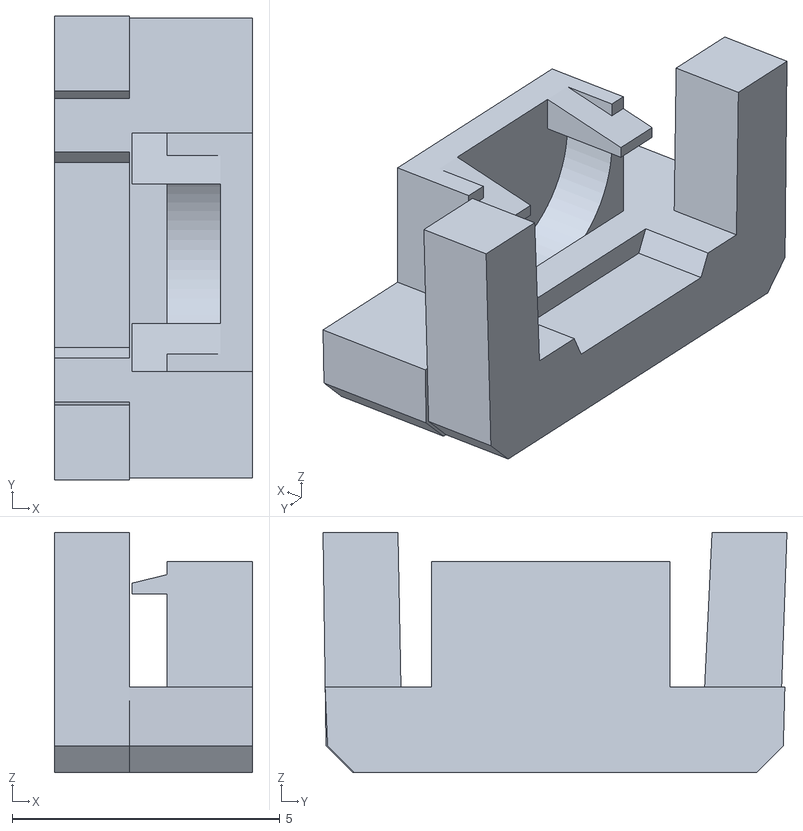
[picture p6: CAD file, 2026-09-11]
tower_clamp_right.stl
3.70 x 8.66 x 4.49

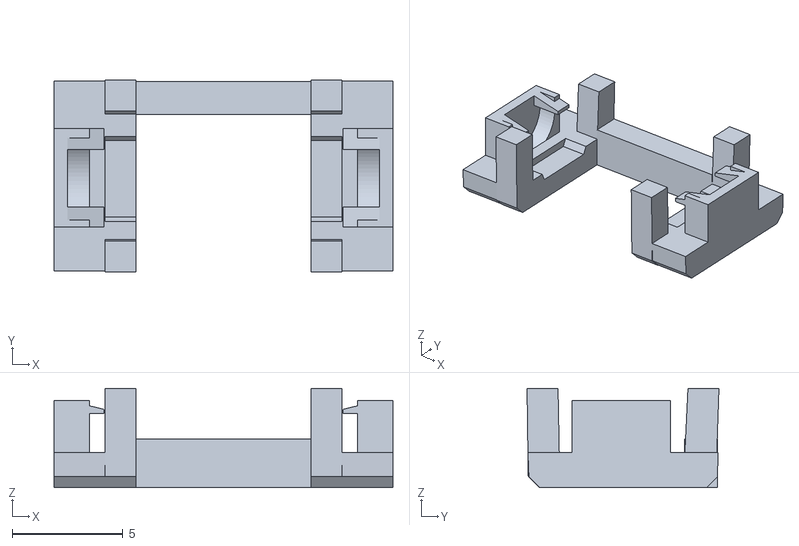
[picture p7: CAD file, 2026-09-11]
tower_clamp_bridge.stl
15.3 x 8.66 x 4.49

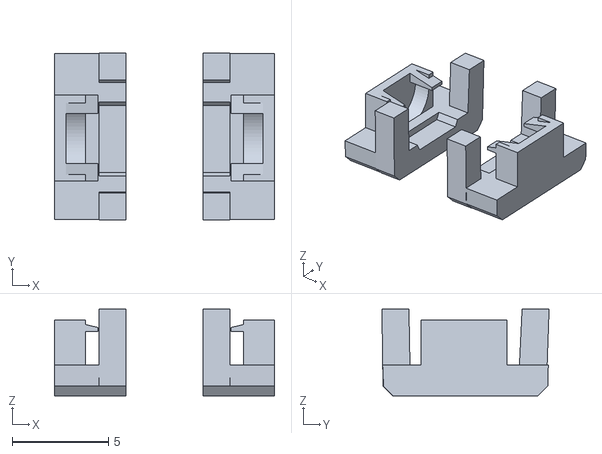
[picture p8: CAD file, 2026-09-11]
tower_clamps_pair.stl
11.4 x 8.66 x 4.49

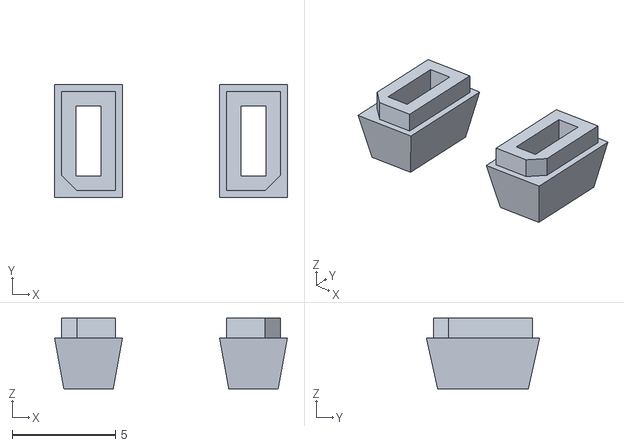
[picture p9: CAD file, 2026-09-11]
slit_inserts_pair.stl
11.3 x 5.50 x 3.42

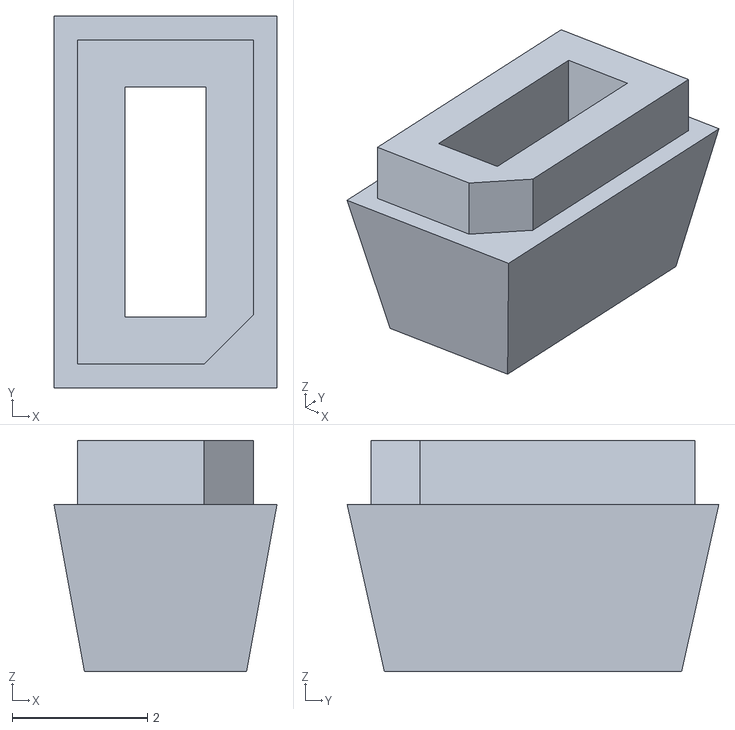
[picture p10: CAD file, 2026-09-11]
slit_insert.stl
3.30 x 5.50 x 3.42

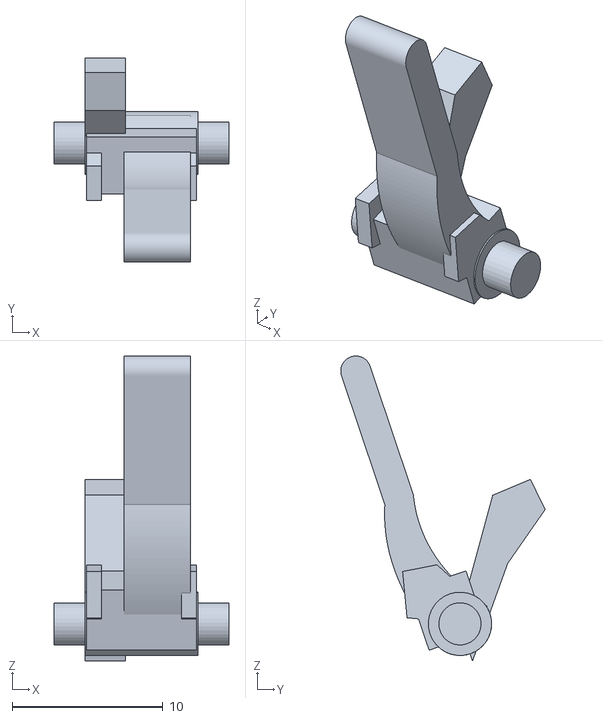
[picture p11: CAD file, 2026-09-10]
shaft_rocker.stl
11.6 x 13.6 x 20.2

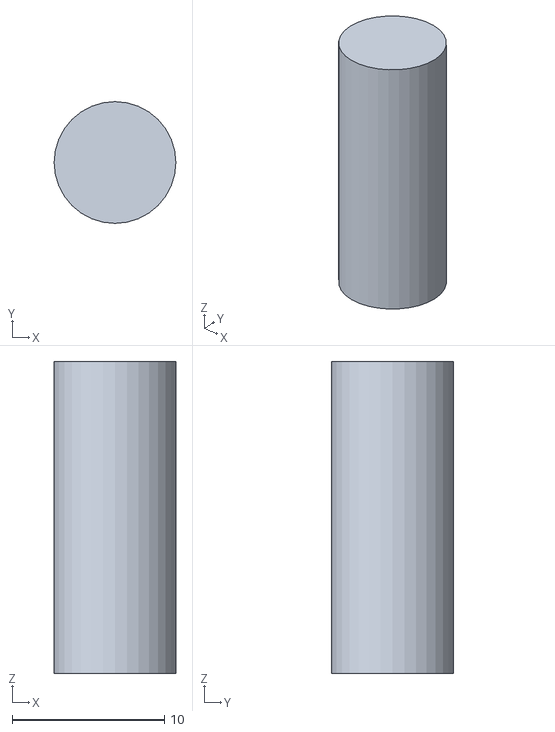
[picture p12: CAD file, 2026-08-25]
cooling_tower.stl
8.00 x 8.00 x 20.5

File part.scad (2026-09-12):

/*
 * Parametric 3D Replacement Part - EXACT SVG Vector Geometry
 * Dimensions in Millimeters (mm)
 */

$fn = 100;

// Dimensions
base_thickness      = 1.0;
outer_wall_height   = 6.77;
outer_wall_thick    = 1.2;
rib_height          = 0.5;
rib_thick           = 0.6;
rib_grid_x          = 5.2;
rib_grid_y          = 3.2;
bracket_h           = 4.6;
bracket_seating_rib_h = 1.15;
bracket_seating_rib_ext = 1.8;
clip_height         = 6.77;
clip_gap_depth      = 3.7;
clip_arm_thick      = 1.2;
clip_arm_width      = 4.2;
clip_slot_clearance = 0.35;
clip_hook_depth     = 2.49;
clip_hook_height    = 1.8;
slit_boss_height    = 2.47;
slit_boss_wall      = 0.8;

// Exact non-circular perimeter points from SVG
svg_perimeter_pts = [
    [20.2000, 3.8500],
    [20.2000, 0.0000],
    [20.2000, -3.8500],
    [18.2060, -3.8500],
    [18.2022, -4.4606],
    [18.1896, -4.5144],
    [18.1684, -4.6017],
    [18.1387, -4.7209],
    [18.1004, -4.8699],
    [18.0534, -5.0470],
    [17.9977, -5.2503],
    [17.9332, -5.4780],
    [17.8599, -5.7283],
    [17.7777, -5.9993],
    [17.6866, -6.2891],
    [17.5865, -6.5960],
    [17.4774, -6.9181],
    [17.3592, -7.2535],
    [17.2318, -7.6005],
    [17.0952, -7.9571],
    [16.9494, -8.3215],
    [16.7942, -8.6919],
    [16.6297, -9.0665],
    [16.4558, -9.4434],
    [16.2724, -9.8208],
    [16.0795, -10.1968],
    [15.8770, -10.5696],
    [15.6649, -10.9373],
    [15.4431, -11.2981],
    [15.1770, -11.7028],
    [14.9002, -12.0861],
    [14.6147, -12.4484],
    [14.3222, -12.7901],
    [14.0246, -13.1117],
    [13.7238, -13.4135],
    [13.4214, -13.6960],
    [13.1195, -13.9596],
    [12.8197, -14.2047],
    [12.5239, -14.4317],
    [12.2340, -14.6410],
    [11.9517, -14.8331],
    [11.6790, -15.0084],
    [11.4176, -15.1672],
    [11.1693, -15.3100],
    [10.9360, -15.4373],
    [10.7195, -15.5494],
    [10.5216, -15.6468],
    [10.3442, -15.7298],
    [10.1890, -15.7989],
    [10.0580, -15.8545],
    [9.9529, -15.8970],
    [9.8756, -15.9269],
    [9.8278, -15.9445],
    [9.8115, -15.9503],
    [9.8115, -18.5387],
    [2.5000, -18.5390],
    [2.5000, -16.6500],
    [-2.5000, -16.6500],
    [-2.5000, -18.5390],
    [-10.6860, -18.5387],
    [-10.6860, -15.9503],
    [-10.9602, -15.7259],
    [-11.2209, -15.5057],
    [-11.4690, -15.2894],
    [-11.7056, -15.0762],
    [-11.9315, -14.8660],
    [-12.1478, -14.6580],
    [-12.3554, -14.4520],
    [-12.5552, -14.2473],
    [-12.7481, -14.0436],
    [-12.9353, -13.8404],
    [-13.1175, -13.6371],
    [-13.2958, -13.4334],
    [-13.4711, -13.2288],
    [-13.6443, -13.0227],
    [-13.8165, -12.8148],
    [-13.9885, -12.6045],
    [-14.1613, -12.3914],
    [-14.3359, -12.1750],
    [-14.5133, -11.9549],
    [-14.6943, -11.7305],
    [-14.8799, -11.5014],
    [-15.0712, -11.2671],
    [-15.2690, -11.0272],
    [-15.4742, -10.7812],
    [-15.6880, -10.5286],
    [-15.9077, -10.2747],
    [-16.1142, -10.0324],
    [-16.3082, -9.8004],
    [-16.4905, -9.5772],
    [-16.6620, -9.3614],
    [-16.8236, -9.1516],
    [-16.9759, -8.9464],
    [-17.1199, -8.7442],
    [-17.2563, -8.5438],
    [-17.3860, -8.3437],
    [-17.5097, -8.1424],
    [-17.6284, -7.9386],
    [-17.7428, -7.7307],
    [-17.8538, -7.5175],
    [-17.9621, -7.2974],
    [-18.0687, -7.0691],
    [-18.1742, -6.8310],
    [-18.2795, -6.5819],
    [-18.3855, -6.3202],
    [-18.4930, -6.0446],
    [-18.6027, -5.7536],
    [-18.7156, -5.4458],
    [-18.8323, -5.1198],
    [-18.9538, -4.7741],
    [-19.0810, -3.8500],
    [-21.0750, -3.8500],
    [-21.0750, 0.0000],
    [-21.0750, 3.8500],
    [-19.0810, 3.8500],
    [-19.0729, 4.5050],
    [-19.0488, 4.5860],
    [-19.0088, 4.7172],
    [-18.9530, 4.8956],
    [-18.8814, 5.1181],
    [-18.7942, 5.3815],
    [-18.6914, 5.6828],
    [-18.5731, 6.0189],
    [-18.4395, 6.3867],
    [-18.2907, 6.7831],
    [-18.1266, 7.2050],
    [-17.9475, 7.6493],
    [-17.7533, 8.1130],
    [-17.5443, 8.5930],
    [-17.3205, 9.0861],
    [-17.0820, 9.5893],
    [-16.8288, 10.0994],
    [-16.5611, 10.6135],
    [-16.2790, 11.1283],
    [-15.9826, 11.6409],
    [-15.6720, 12.1481],
    [-15.3471, 12.6469],
    [-15.0083, 13.1341],
    [-14.6555, 13.6066],
    [-14.2888, 14.0614],
    [-13.9415, 14.4420],
    [-13.5572, 14.8030],
    [-13.1403, 15.1449],
    [-12.6952, 15.4680],
    [-12.2262, 15.7726],
    [-11.7376, 16.0591],
    [-11.2339, 16.3278],
    [-10.7193, 16.5790],
    [-10.1982, 16.8131],
    [-9.6750, 17.0304],
    [-9.1540, 17.2313],
    [-8.6395, 17.4160],
    [-8.1360, 17.5850],
    [-7.6478, 17.7385],
    [-7.1792, 17.8769],
    [-6.7345, 18.0006],
    [-6.3182, 18.1097],
    [-5.9346, 18.2048],
    [-5.5880, 18.2861],
    [-5.2828, 18.3540],
    [-5.0233, 18.4088],
    [-4.8139, 18.4509],
    [-4.6589, 18.4805],
    [-4.5628, 18.4980],
    [-4.1000, 18.5040],
    [-4.1000, 20.0080],
    [4.1000, 20.0080],
    [4.1000, 18.5040],
    [3.7160, 18.5022],
    [3.7915, 18.4968],
    [3.9142, 18.4865],
    [4.0814, 18.4701],
    [4.2905, 18.4464],
    [4.5389, 18.4143],
    [4.8239, 18.3727],
    [5.1430, 18.3204],
    [5.4936, 18.2562],
    [5.8729, 18.1791],
    [6.2785, 18.0880],
    [6.7076, 17.9815],
    [7.1576, 17.8587],
    [7.6261, 17.7183],
    [8.1102, 17.5593],
    [8.6074, 17.3805],
    [9.1151, 17.1807],
    [9.6306, 16.9588],
    [10.1514, 16.7137],
    [10.6748, 16.4442],
    [11.1982, 16.1492],
    [11.7190, 15.8275],
    [12.2345, 15.4780],
    [12.7422, 15.0996],
    [13.2394, 14.6911],
    [13.7423, 14.2177],
    [14.2108, 13.7232],
    [14.6460, 13.2111],
    [15.0492, 12.6848],
    [15.4216, 12.1477],
    [15.7642, 11.6033],
    [16.0783, 11.0550],
    [16.3652, 10.5063],
    [16.6258, 9.9606],
    [16.8616, 9.4213],
    [17.0735, 8.8919],
    [17.2629, 8.3758],
    [17.4308, 7.8764],
    [17.5785, 7.3973],
    [17.7072, 6.9417],
    [17.8180, 6.5133],
    [17.9121, 6.1153],
    [17.9908, 5.7513],
    [18.0551, 5.4246],
    [18.1062, 5.1388],
    [18.1455, 4.8972],
    [18.1739, 4.7034],
    [18.1928, 4.5606],
    [18.2032, 4.4725],
    [18.2060, 3.8500],
    [20.2000, 3.8500]
];

module base_perimeter_2d() {
    polygon(points = svg_perimeter_pts);
}

module base_plate_2d() {
    difference() {
        base_perimeter_2d();
        
        // Top-Right rectangular hole
        translate([10.28 - 5.35/2, 10.83 - 4.51/2])
            square([5.35, 4.51]);
            
        // Left Polarized Detent Socket (X = -7.853mm, bottom-left chamfer)
        translate([-7.853, -13.589])
            polygon(points = [
                [-1.450 + 0.85, -2.550],
                [1.450, -2.550],
                [1.450, 2.550],
                [-1.450, 2.550],
                [-1.450, -2.550 + 0.85]
            ]);
            
        // Right Polarized Detent Socket (X = +8.453mm, bottom-right chamfer)
        translate([8.453, -13.589])
            polygon(points = [
                [-1.450, -2.550],
                [1.450 - 0.85, -2.550],
                [1.450, -2.550 + 0.85],
                [1.450, 2.550],
                [-1.450, 2.550]
            ]);
    }
}

module bracket_seating_ribs_2d() {
    for (y = [5.25, 1.95, -1.35, -4.65]) {
        // Left Pair
        translate([-9.857, y - 0.6/2])
            square([1.8, 0.6]);
        translate([-4.501, y - 0.6/2])
            square([1.8, 0.6]);
        // Right Pair
        translate([2.701, y - 0.6/2])
            square([1.8, 0.6]);
        translate([8.057, y - 0.6/2])
            square([1.8, 0.6]);
    }
}

module complete_part() {
    union() {
        // Base plate
        linear_extrude(height = base_thickness)
            base_plate_2d();
            
        // 100% UNTOUCHED Outer Wall with constant thickness following exact perimeter
        difference() {
            linear_extrude(height = outer_wall_height)
                base_plate_2d();
            translate([0, 0, base_thickness])
                linear_extrude(height = outer_wall_height + 1)
                    offset(r = -outer_wall_thick)
                        base_plate_2d();
        }
        
        // Bracket Seating Ribs (1.15mm tall on 1.0mm base)
        translate([0, 0, base_thickness])
            linear_extrude(height = bracket_seating_rib_h)
                bracket_seating_ribs_2d();
    }
}

complete_part();

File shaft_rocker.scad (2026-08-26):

// Parametric OEM 3-Rib Shaft & Rocker Mechanism for Kia Socket Enclosure
// Generated by build_shaft.py

$fn = 64;

// Global Parameters (mm)
total_axle_len = 11.5;
hub_w = 7.5;
pin_d = 2.8;
pin_len = 2.00;
hub_d = 4.2;

plunger_reach_below_z = 6.5;
plunger_w = 4.4;
hole_x_c = 10.284;

cam_w = 2.7;
cam_x_c = 6.28;
x_c = 9.25;
y_axle = 9.279;
z_axle = 12.59;

// 2D Profile: Option 1 Direct Straight Belly Cam
poly_cam_pts = [
    [9.279, 12.59],
    [9.279, 15.19],
    [5.00, 9.80],
    [1.50, 7.20],
    [1.80, 5.00],
    [4.50, 5.20],
    [7.779, 10.09]
];

module oem_shaft_rocker() {
    // Left Pivot Pin
    translate([x_c - hub_w/2 - pin_len/2, y_axle, z_axle])
        rotate([0, 90, 0])
            cylinder(r = pin_d/2, h = pin_len, center = true);
            
    // Right Pivot Pin
    translate([x_c + hub_w/2 + pin_len/2, y_axle, z_axle])
        rotate([0, 90, 0])
            cylinder(r = pin_d/2, h = pin_len, center = true);
            
    // Central Hub Barrel
    translate([x_c, y_axle, z_axle])
        rotate([0, 90, 0])
            cylinder(r = hub_d/2, h = hub_w, center = true);
            
    // Direct Straight Belly Cam Tab
    translate([cam_x_c - cam_w/2, 0, 0])
        rotate([0, -90, 0])
            rotate([0, 0, 90])
                linear_extrude(height = cam_w)
                    polygon(poly_cam_pts);
}

oem_shaft_rocker();

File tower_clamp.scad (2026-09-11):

// Kia EV6 Outlet Interlock - Anti-Spreading Tower Prong Clamp (Option 2)
// Generated by build_clamp.py

$fn = 64;

// Global parameters
z_top = 14.09;
roof_thick = 1.6;
wall_thick = 1.4;
side_thick = 1.6;
pin_clearance_r = 1.85;
y_axle = 9.279;
z_axle = 12.59;

module tower_clamp_left() {
    // Left Tower Clamp with outer side retention ears and zero pin contact
    difference() {
        union() {
            // Main U-saddle
            translate([3.90, 0, 0])
                linear_extrude(height = 1.475)
                    polygon(points = [
                        [5.314, 11.20], [5.360, 14.59], [5.760, 14.99],
                        [13.370, 14.99], [13.370, 14.59], [13.498, 11.20],
                        [12.698, 11.20], [12.348, 11.55], [12.220, 14.09],
                        [11.208, 14.09], [10.908, 14.17], [10.758, 14.02],
                        [7.800, 14.02], [7.650, 14.17], [7.350, 14.09],
                        [6.510, 14.09], [6.464, 11.55], [6.114, 11.20]
                    ]);
            // Outer side wall
            translate([3.00, 0, 0])
                linear_extrude(height = 0.90)
                    difference() {
                        polygon(points = [
                            [5.314, 12.10], [5.360, 14.59], [5.760, 14.99],
                            [13.370, 14.99], [13.370, 14.59], [13.498, 12.10],
                            [10.75, 12.10], [7.80, 12.10]
                        ]);
                        // Pin clearance arch
                        translate([y_axle, z_axle])
                            circle(r = pin_clearance_r);
                    }
        }
    }
}

tower_clamp_left();

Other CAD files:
tower_clamp_left.stl
complete_assembly.obj
cooling_tower.obj
part.obj
shaft_rocker.obj
shaft_rocker_assembled.obj
slit_insert.obj
tower_clamp.obj
tower_clamp_bridge.obj
tower_clamp_left.obj
tower_clamp_right.obj

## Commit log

2026-08-16 Initial commit: Complete parametric 3D CAD model generator with exact non-circular geometry, shaft towers, guide brackets, curved snap clips, and center curved feature
    [part.obj, part.scad, part.stl]
2026-08-16 Align inset bottom exterior wall notch directly with bottom central arch sidewalls
    [part.obj, part.scad, part.stl]
2026-08-16 Update bottom inset notch to Config 1: outer walls aligned with arch inner walls at X = +-2.50mm
    [part.obj, part.scad, part.stl]
2026-08-16 Set bottom central arch total outer height to 7.95mm
    [part.obj, part.stl]
2026-08-16 Update shaft cradle on towers to wrap-around retention geometry with 1.65mm throat opening
    [part.obj, part.stl]
2026-08-16 Separate backside slit walls into independent 3D-printable insert parts with indexing registration keys
    [complete_assembly.obj, complete_assembly.stl, part.stl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]
2026-08-17 Fix slit insert mesh to be 100% monolithic watertight solid with solid shoulder and zero floating gap
    [complete_assembly.obj, complete_assembly.stl, slit_insert.obj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]
2026-08-22 Update through-slits to 1.05x3.35mm for 0.75x3.0mm mating part and arrange complete assembly flat on Z=0 build plane
    [complete_assembly.obj, complete_assembly.stl, part.obj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]
2026-08-22 Refine print tolerances, snap tab positioning, detent sockets, and cooling tower for re-print
    - Reduce snap clip flex slot clearance to 0.35mm optimized for 0.4mm nozzle
    - Reposition bottom snap tabs to 214.5 deg and 325.5 deg (halfway between side ears and bottom tabs)
    - Add sacrificial cooling tower (dia 8mm x 14mm) to print plate to prevent tower tip overheating
    - Add 2.00x4.30mm female detent sockets in baseplate floor for press-fit slit inserts
    - Shift slit and detent socket Y position +1.0mm in +Y (Option 1: Y in [-15.34, -12.00mm])
    - Rebuild all CAD STLs, OBJs, OpenSCAD files, and dimensioned previews
    - Note: Printing test revision again
    [complete_assembly.obj, complete_assembly.stl, cooling_tower.obj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]
2026-08-23 Enlarge flexible snap clip width to 4.20mm for 5mm mating holes
    - Widen snap clip cantilever beam from 3.00mm to 4.20mm (CLIP_ARM_WIDTH = 4.20)
    - Leaves 0.80mm total margin (0.40mm per side clearance) for smooth insertion in 5.0mm holes
    - Retain 0.35mm flex slot clearance on either side of each tab
    - Rebuild part.stl, complete_assembly.stl, OpenSCAD, and visual inspection renders
    - Note: Did not print yet
    [complete_assembly.obj, complete_assembly.stl, part.obj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]
2026-08-23 Reinforce shaft rocker, adjust bracket top gaps, expand detent socket clearance, and organize testing directory
    [complete_assembly.obj, complete_assembly.stl, part.obj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]
2026-08-23 Reinforce shaft support towers and retention cradles
    - Flared trapezoidal tower profile in Y-Z: Base 7.00mm (Y: 4.20 to 11.20mm), Top 5.73mm (Y: 4.80 to 10.53mm)
    - Increase solid retention material around cradle by +45% and base bending stiffness by +200%
    - Tune cradle throat constriction to 1.78mm (0.12mm gentle snap with dia 1.90mm shaft, reducing insertion stress by 52%)
    - Maintain 305.8 deg permanent wrap-around retention angle
    - Extend left triangular buttress struts up to Z = 13.20mm (cradle center level)
    - Increase tower wall thickness to 1.50mm in X
    - Synchronize build_shaft.py collar positions and bearing lands with reinforced towers
    - Rebuild part.stl, complete_assembly.stl, shaft_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
    [complete_assembly.obj, complete_assembly.stl, part.obj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]
2026-08-23 Reinforce shaft retention cradles, enlarge slits, and optimize clearances
    - Narrow cradle throat to 1.52mm (0.38mm firm snap interference, 261 deg wrap angle) to permanently lock shaft and prevent popping out
    - Enlarge slit and insert through-channel to 1.20mm x 3.50mm for 0.77mm x 3.10mm mating blade (+0.43mm in X, +0.40mm in Y sliding clearance)
    - Shift left detent socket and slit 0.60mm inward to X = -7.853mm to center blade in through-slit
    - Eliminate Bracket 3 interference with Left Tower (0.40mm air gap, hook tip at X = 3.50mm, tower front flank at Y = 4.60mm, guide channel opened to 4.35mm)
    - Trim side ear width in Y to 7.70mm (0.60mm sliding clearance in 8.30mm enclosure guide slots)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
    [complete_assembly.obj, complete_assembly.stl, part.obj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]
2026-08-23 Shift shaft towers in +Y to align front strut with top of Bracket 3, restore Bracket 3 full slot width, and widen input cam arm +2mm on right
    [complete_assembly.obj, complete_assembly.stl, part.obj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]
2026-08-23 Implement reverse-engineered OEM 3-rib shaft rocker on oem-shaft-rocker branch
    [complete_assembly.obj, complete_assembly.stl, shaft_rocker.obj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]
2026-08-24 Speculative: Enlarge shaft to dia 2.80mm, upgrade tower cradles to dia 3.00mm, and set 105 deg direct input cam
    - Enlarge shaft axle pins from dia 1.90mm to dia 2.80mm (+47% diameter, 4.72x torsional rigidity)
    - Enlarge tower cradle sockets to dia 3.00mm (0.20mm clearance)
    - Widen tower snap-fit retention throat to 2.45mm (0.35mm positive interference, >250 deg wrap angle)
    - Enlarge central hub barrel to dia 4.20mm across 7.50mm span
    - Widen plunger blade to 4.40mm centered in 5.35mm through-hole
    - Update tower height to 14.09mm and sacrificial cooling tower to 14.50mm
    - Set input cam to 105.0 deg bellcrank angle originating directly off shaft hub with zero gap
    - Rebuild all production STL,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
    [complete_assembly.obj, complete_assembly.stl, cooling_tower.obj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]
2026-08-24 Align input cam top surface 100% flush with top apex of shaft hub
    - Make input cam top surface tangent to the cylindrical shaft apex at Z = 14.690mm (0.00mm step)
    - Maintain exact 105.0 deg bellcrank angle and 2.80mm solid arm thickness
    - Rebuild shaft_rocker.stl, complete_assembly.stl, and labeled blueprints
    [complete_assembly.obj, complete_assembly.stl, shaft_rocker.obj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]
2026-08-24 Align lowest extent of shaft towers in Y exactly with Bracket 3 top inner wall at Y=6.250mm
    - Shift tower base to Y in [6.250, 12.850]mm, aligning lowest extent exactly with Bracket 3 top inner wall at Y = 6.250mm
    - Keep both Left and Right towers in perfect symmetric alignment
    - Update shaft axle pivot center to Y = 9.279mm, Z = 12.590mm
    - Update left tower front buttress strut to start at Y = 6.250mm
    - Rebuild all production STL, OBJ, SCAD models, blueprints, and verification tests
    [complete_assembly.obj, complete_assembly.stl, part.obj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]
2026-08-24 Align bottom of left tower front buttress exactly with Bracket 3 top inner wall at Y=6.250mm
    - Set Left Tower front buttress base to start at Y = 6.250mm, exactly aligned with Bracket 3 top inner wall
    - Slopes smoothly into Left Tower front face at Y = 7.171mm, Z = 13.70mm with zero sliding channel encroachment
    - Keep main tower columns and shaft pivot axis at Y = 10.200mm centered directly over through-hole
    - Rebuild all production CAD models, blueprints, and verification tests
    [complete_assembly.obj, complete_assembly.stl, part.obj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]
2026-08-24 Shift entire tower assembly and shaft by -0.921mm in Y using bracket 3 inner wall reference
    - Shift both Left and Right towers, cradles, and shaft pivot axis by -0.921mm in Y (Base: Y in [6.250, 12.850]mm, Shaft: Y = 9.279mm)
    - Aligns the tower assembly reference front with Bracket 3 top inner wall at Y = 6.250mm
    - Rebuild and verify all production deliverables
    [complete_assembly.obj, complete_assembly.stl, part.obj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]
2026-08-24 Tighten tower retention cradle throat to 2.05mm for 0.75mm positive snap lock
    - Constrict cradle throat gap from 2.45mm to 2.05mm (2.14x deeper retention lip of 0.375mm per side)
    - Increase wrap angle to 273.8 deg (>76% full circle wrap) with 45-deg lead-in funnel
    - Prevent shaft pop-out under operational forces while retaining smooth press-fit insertion
    - Rebuild all CAD deliverables, blueprints, and verification tests
    [complete_assembly.obj, complete_assembly.stl, part.obj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]
2026-08-25 v6: Relax tower snap throat to 2.60mm and reorient shaft rocker cam-flat to eliminate trapped support
    [complete_assembly.obj, complete_assembly.stl, part.obj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]
2026-08-25 v6: Increase sacrificial cooling tower height to 20.50mm to cover shaft rocker apex
    [complete_assembly.obj, complete_assembly.stl, cooling_tower.obj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]
2026-08-25 Printed v7 lever: extended sacrificial heat break tower to 20.50mm to match full print height
2026-08-25 Implement Option 3: Convex crowned cam profile (+0.45mm crown arc) and +1.00mm clip extension
    [complete_assembly.obj, complete_assembly.stl, part.obj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]
2026-08-25 feat(testing): add 3D/2D kinematic modeling and simulation for plug insertion
    - Implement high-performance vectorized kinematic solver (`model_plug_insertion.py`) to simulate NEMA 5-15 plug blade insertion and rocker rotation
    - Verify rigid-body rotation direction, mechanical advantage (4.64x), pressure angle, and jam-free contact mechanics
    - Add tolerance sweep analyzing lateral and longitudinal plug play envelope in bracket channels
    - Render 4-panel diagnostic blueprint (`plug_insertion_simulation.png`) and 3D isometric perspective view (`3d_plug_insertion_view.png`)
    - Add standalone kinematic direction verification script (`verify_kinematic_direction.py`)
2026-08-26 test(clearance): verify blade-to-curved-feature clearance and document future guide tweak
    - Add check_curved_feature_clearance.py and curved_feature_blade_clearance.png confirming a +2.16mm air gap between the hot plug blade and the 10.50mm center curved feature
    - Add analyze_curved_feature_role.py evaluating tilted plug insertion, fail-safe backstop limits (>7.5° tilt), and dielectric barrier role
    - Update README.md with Section 7 documenting the plug insertion verification suite and potential lead-in funnel bevel tweaks
2026-08-26 feat: v8 - Arched full-width rocker cam for OEM brass pinching contact mechanism
    [complete_assembly.obj, complete_assembly.stl, part.obj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]
2026-08-26 feat: v8 - Direct straight belly cam for OEM brass pinching mechanism
    [complete_assembly.obj, complete_assembly.stl, shaft_rocker.obj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]
2026-08-30 feat: implement relaxed bracket tolerances, 1.15mm seating ribs, and polarized chamfered slit inserts
    [complete_assembly.obj, complete_assembly.stl, part.obj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]
2026-09-10 Add unified monolithic bridge clamp and optimize sliceable features
    - Implement Unified 1-Piece Monolithic Bridge Clamp (tower_clamp_bridge.stl)
    joining Left and Right clamps across a 14.1mm rigid gantry to prevent
    tower prong spreading with zero pin friction.
    - Enlarge slit insert registration key to 2.60x4.80mm with 0.70mm solid walls
    and 0.60mm polarized bevel to prevent key being dropped during slicing.
    - Enlarge tower snap ledges to +0.70mm protrusion and 0.60mm vertical shelf
    with 0.65mm matching clamp undercut hooks for robust FDM mechanical retention.
    - Verify 100% collision-free fitment with Left Tower triangular buttress struts
    and 0-20 deg dynamic rocker rotation sweep.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
    [complete_assembly.obj, complete_assembly.stl, part.obj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]
2026-09-11 Remove slit insert bottom-right corner lip interference and export polarized pair
    [complete_assembly.obj, complete_assembly.stl, part.obj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]
2026-09-11 fix: restore intact slit insert body, isolate registration lip chamfer, and clear floor socket
    [complete_assembly.obj, complete_assembly.stl, part.obj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]
2026-09-11 feat: reinforce tower prong clamp stiffness and expand pin clearance margin
    - Thicken bridge roof to 1.60mm (+78%, 5.6x bending stiffness) and side cheeks to 1.60mm (4.1x stiffness)
    - Implement dual-layer cheek with solid continuous 0.60mm outer backplate to prevent flexure
    - Replace downward keel with upward pin relief pocket at Z = 14.50mm (+0.51mm vertical air gap)
    - Enlarge radial pin arch to R = 1.85mm (+0.45mm air gap) to accommodate support-printed rocker artifacts
    - Inset saddle to X = 5.30mm/13.20mm for 0.20mm axial margin to central hub barrel
    - Adjust snap hook shelf to Z = 12.35mm (+0.05mm clearance) for positive tactile mechanical click
    - Regenerate all tower clamp deliverables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
    [complete_assembly.obj, complete_assembly.stl, tower_clamp.obj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]
2026-09-12 feat: reinforce center curved feature to solid D-shape with flat solid base
    [complete_assembly.obj, complete_assembly.stl, part.obj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]
2026-09-12 feat: calibrate snap clip overhang to 2.49mm and add twin-prong breakaway support
    [complete_assembly.obj, complete_assembly.stl, part.obj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]
